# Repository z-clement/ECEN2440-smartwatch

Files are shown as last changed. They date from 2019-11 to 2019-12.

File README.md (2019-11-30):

# ECEN2440-smartwatch

The final project for ECEN2440 Embedded Systems. Our group decided to make a smartwatch that has a touchscreen display
with the capabilities to set an alarm and timer using bluetooth.

The project uses an MSP432 as the microcontroller which communicates via UART with the display and bluetooth module.

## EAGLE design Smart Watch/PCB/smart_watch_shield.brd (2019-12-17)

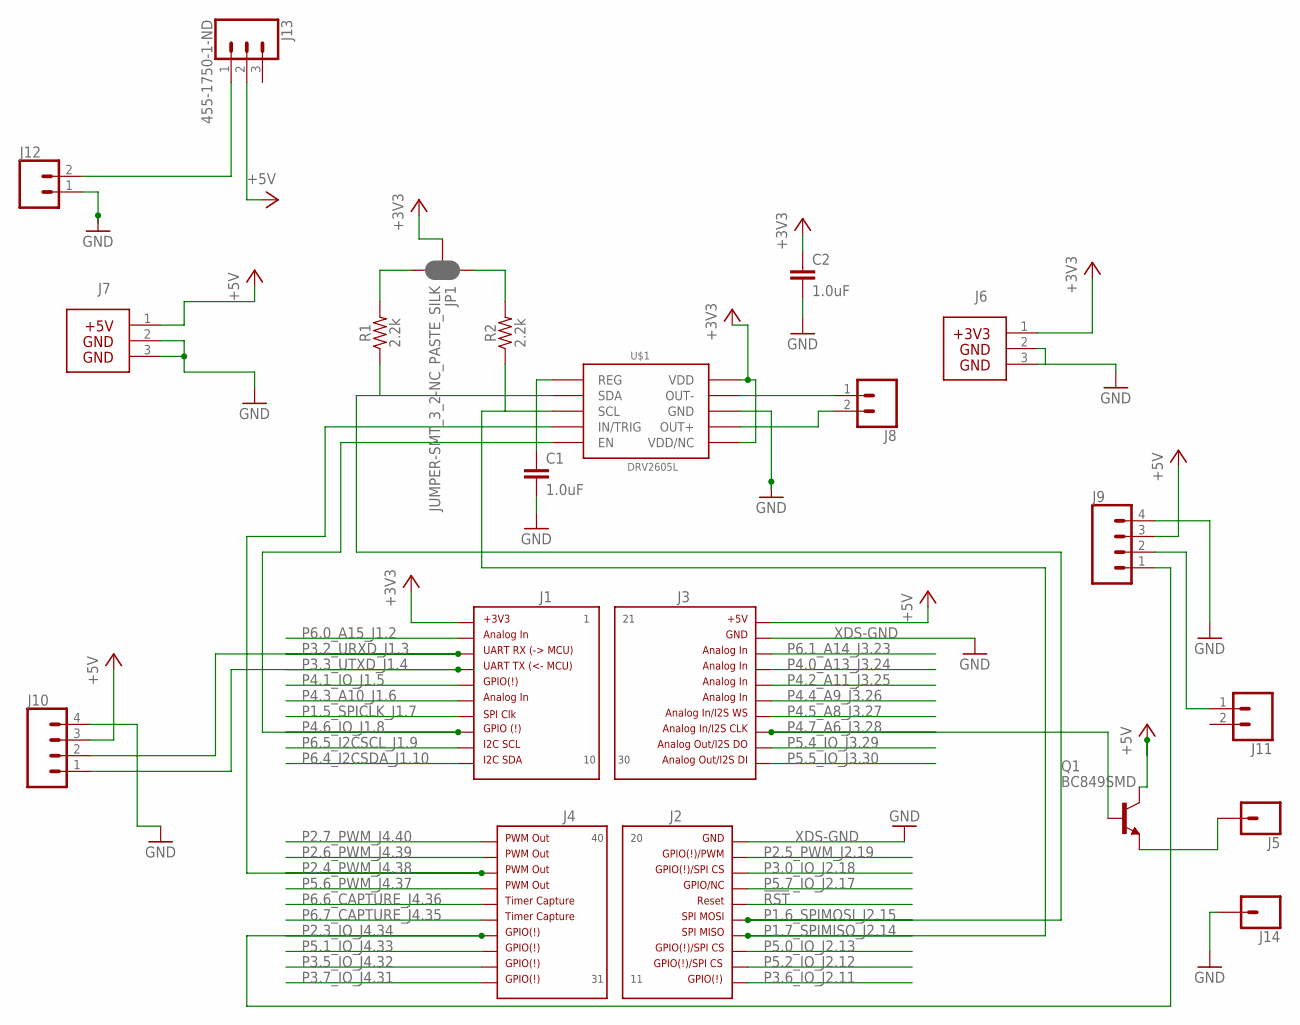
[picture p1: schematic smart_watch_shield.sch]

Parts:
C1, C2: 1.0uF; 0805
J1: HEADER1X10-J1SILK_LABELS; J1
J2: HEADER1X10-J2SILK_LABELS; J2
J3: HEADER1X10-J3; J3
J4: HEADER1X10-J4SILK_LABELS; J4
J5, J14: CONN_01; 1X01
J6: HEADER 1X03; 3PIN_PWR_3V3
J7: BP_HEADERS_PWR_5V; 3PIN_PWR_5V
J8, J11, J12: CONN_02; 1X02
J9, J10: CONN_04PTH; 1X04
J13: 455-1750-1-ND; 1X03
JP1: JUMPER-SMT_3_2-NC_PASTE_SILK; SMT-JUMPER_3_2-NC_PASTE_SILK
Q1: BC849SMD; SOT23-BEC
R1, R2: 2.2k; 0603
U$1: DRV2605L; VSSOP-10

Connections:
!RST: J2.16
+3V3: C2.1, J1.1, J6.1, JP1.2, U$1.P$6 (VDD/NC), U$1.P$10 (VDD)
+5V: J3.21, J7.1, J9.3, J10.3, J13.2, Q1.C
GND: C1.2, C2.2, J6.2, J6.3, J7.2, J7.3, J9.4, J10.4, J12.1, J14.1, U$1.P$8 (GND)
unnamed: JP1.3, R1.2
unnamed: JP1.1, R2.2
unnamed: J8.1, U$1.P$9 (OUT-)
unnamed: J9.2, J11.1
unnamed: J12.2, J13.1
unnamed: J5.1, Q1.E
unnamed: C1.1, U$1.P$1 (REG)
unnamed: J8.2, U$1.P$7 (OUT+)
P1.5_SPICLK_J1.7: J1.7
P1.6_SPIMOSI_J2.15: J2.15, R1.1, U$1.P$3 (SDA)
P1.7_SPIMISO_J2.14: J2.14, R2.1, U$1.P$2 (SCL)
P2.3_IO_J4.34: J4.34, J9.1
P2.4_PWM_J4.38: J4.38, U$1.P$4 (IN/TRIG)
P2.5_PWM_J2.19: J2.19
P2.6_PWM_J4.39: J4.39
P2.7_PWM_J4.40: J4.40
P3.0_IO_J2.18: J2.18
P3.2_URXD_J1.3: J1.3, J10.2
P3.3_UTXD_J1.4: J1.4, J10.1
P3.5_IO_J4.32: J4.32
P3.6_IO_J2.11: J2.11
P3.7_IO_J4.31: J4.31
P4.0_A13_J3.24: J3.24
P4.1_IO_J1.5: J1.5
P4.2_A11_J3.25: J3.25
P4.3_A10_J1.6: J1.6
P4.4_A9_J3.26: J3.26
P4.5_A8_J3.27: J3.27
P4.6_IO_J1.8: J1.8, U$1.P$5 (EN)
P4.7_A6_J3.28: J3.28, Q1.B
P5.0_IO_J2.13: J2.13
P5.1_IO_J4.33: J4.33
P5.2_IO_J2.12: J2.12
P5.4_IO_J3.29: J3.29
P5.5_IO_J3.30: J3.30
P5.6_PWM_J4.37: J4.37
P5.7_IO_J2.17: J2.17
P6.0_A15_J1.2: J1.2
P6.1_A14_J3.23: J3.23
P6.4_I2CSDA_J1.10: J1.10
P6.5_I2CSCL_J1.9: J1.9
P6.6_CAPTURE_J4.36: J4.36
P6.7_CAPTURE_J4.35: J4.35
XDS-GND: J2.20, J3.22

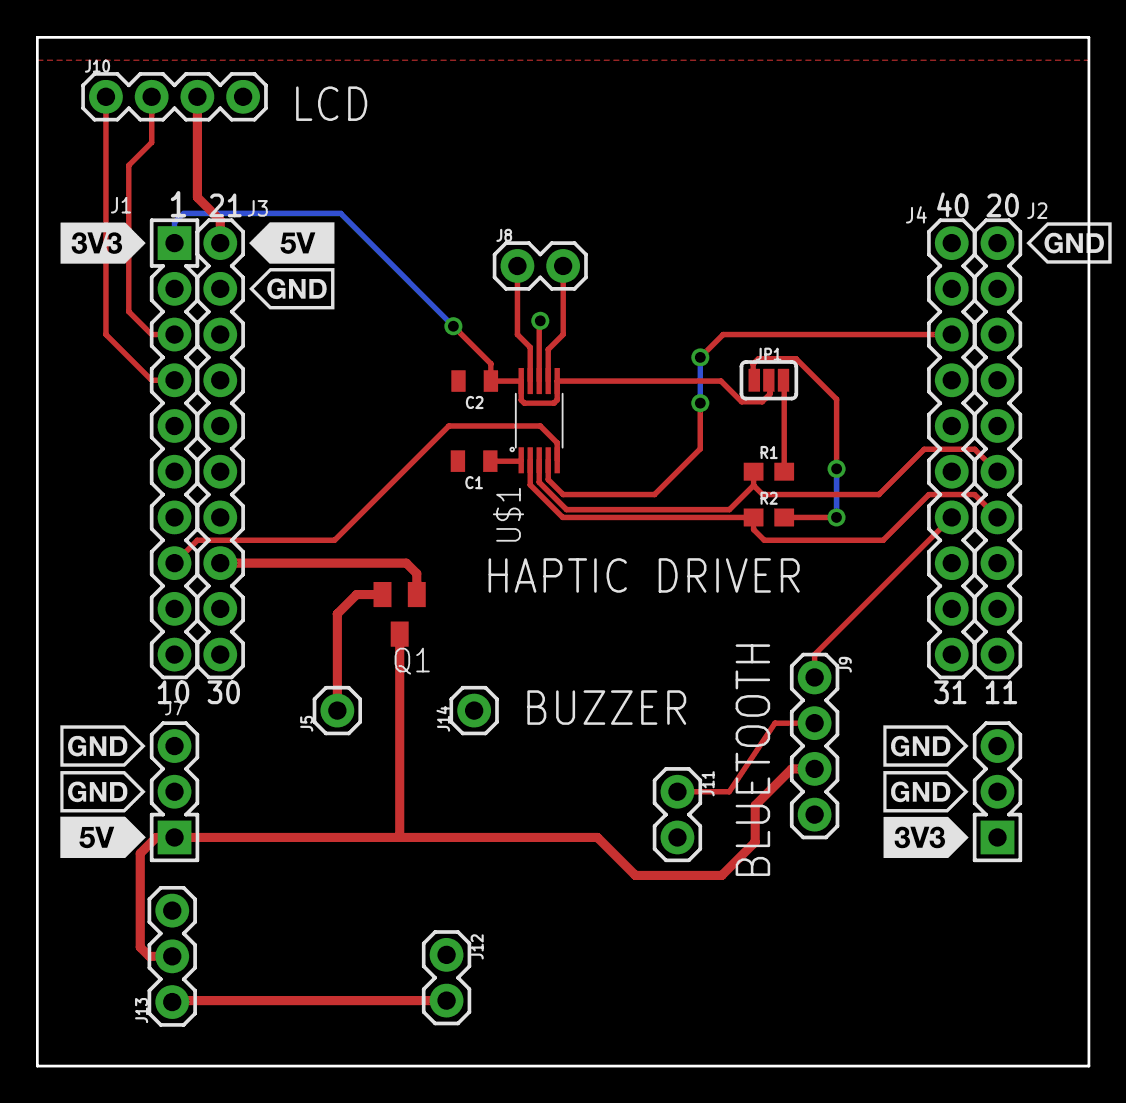
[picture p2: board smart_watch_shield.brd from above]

Board: 2 copper layers, 58.4 x 57.1 mm, 21 parts (1 on the bottom side), 20 nets.

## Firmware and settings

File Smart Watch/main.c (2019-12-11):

#include "msp.h"
#include "uart.h"
#include "bluetooth.h"
#include "circularBuf.h"
#include "screenRefresh.h"
#include "rtc.h"
#include "changeTime.h"
#include "alarmButton.h"
#include "alarm.h"


/**
 * main.c
 */


// Variables to send the current time to the screen
volatile uint8_t sec = 0x00;
volatile uint8_t min = 0x00;
volatile uint8_t hour = 0x00;
volatile uint8_t day = 0x00;
volatile uint8_t month = 0x00;
volatile uint32_t year = 0x00;
volatile uint8_t dow = 0x00;

// Flags for interrupts so we aren't processing a lot of code while in the interrupts
volatile uint8_t MINUTEFLAG = 0;
volatile uint8_t RDYFLAG = 0;
volatile uint8_t ALARMFLAG = 0;
volatile uint8_t TIMERFLAG = 0;
volatile uint8_t RX2FLAG = 0;
volatile uint8_t TX2FLAG = 0;
volatile uint8_t RX1FLAG = 0;
volatile uint8_t TX1FLAG = 0;
volatile uint8_t CLOCKSETFLAG = 0;
volatile uint8_t ALARMSETFLAG = 0;
volatile uint8_t TIMERSETFLAG = 0;
volatile uint8_t ALARMBUTTONFLAG = 0;

// UART variables needed in bluetooth.c and the screen files
EUSCI_A_Type * bluetooth_port = EUSCI_A1;
uint8_t screenData = 0;

void main(void)
{
    WDT_A->CTL = WDT_A_CTL_PW | WDT_A_CTL_HOLD;		// stop watchdog timer

    __enable_irq();

    // Configure buzzer and haptic driver
    config_alarm_notifications();

    // Configure UART for the screen
	EUSCI_A_Type * uart_portScreen = EUSCI_A2;
	config_uart(uart_portScreen);

    // Configure UART for bluetooth
    config_uart(bluetooth_port);

    // Create a circular buffer for bluetooth and screen receiving
    circ_buf_t * bluetoothBuffer = createBuffer(5);
    circ_buf_t * displayBuffer = createBuffer(2);

    // Create a buffer to send a bluetooth message when an alarm fires
    circ_buf_t * alarmBuffer = createBuffer(6);

    // Sends "Connected" over bluetooth to verify the watch is connected
    circ_buf_t * testBuffer = createBuffer(9);
    addMultipleToBuffer(testBuffer, "Connected", 9);
    uart_transmit_buffer(testBuffer, bluetooth_port);
    deleteBuffer(testBuffer);

    // Default time is 12:00:00 on 12/08/2020
    const RTC_C_Calendar currentTime =
    {
         0x00,       // Seconds
         0x00,       // Minutes
         0x12,       // Hours
         0x00,       // Day of week (unused in our watch)
         0x8,        // Day of month
         0x12,       // Month
         0x2020      // Year
    };

    // Configure the RTC with the above time in BCD format
    RTC_config(&currentTime, RTC_C_CTL13_BCD);; // configure the rtc clock and interupts

    // Update the screen with the default time
    clockUpdate();
    changeAllTime(uart_portScreen);

    while(1){
        // Read in from bluetooth UART
        if (RX1FLAG) {
            uart_read_to_buffer(bluetoothBuffer, bluetooth_port);
            if (isBufferFull(bluetoothBuffer)) {
                decode_bluetooth(bluetoothBuffer);
            }
        }
        // Read in from screen UART
        if (RX2FLAG){
            screenReadRegister();
            decode_screen(uart_portScreen);
        }
        // Alarm or timer goes off
        if (ALARMFLAG) {
           // Turn on the Piezo buzzer and haptic driver
           trigger_alarm();
           ALARMFLAG = 0;
           gotoAlarmButton(uart_portScreen);
           // Check if it was a timer, if so disable alarms so the timer doesn't repeat
           if (TIMERFLAG) {
               RTC_C->AMINHR = 0x0000;
               RTC_C->ADOWDAY = 0x0000;
               TIMERFLAG = 0;
               addMultipleToBuffer(alarmBuffer, "Timer", 5);
           } else {
               addMultipleToBuffer(alarmBuffer, "Alarm", 5);
           }

           // Send a message over bluetooth indicating the alarm/timer finished
           uart_transmit_buffer(alarmBuffer, bluetooth_port);
        }
        // Second ticked by, time must be updated
        if (RDYFLAG) {
            clockUpdate();
            // Only update the time if an alarm is not currently going off
            if (ALARMBUTTONFLAG == 0){
                changeAllTime(uart_portScreen);
            }
            RDYFLAG = 0;
        }
    }
}

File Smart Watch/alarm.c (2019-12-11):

/*
 * alarm.c
 *
 *  Created on: Dec 4, 2019
 *      Author: Zac
 */

#include "msp.h"
#include "drv2605l.h"
#include "gpio.h"
#include "i2c.h"
#include "pwm.h"
#include "alarm.h"

// Configure the DRV, LRA, and buzzer
void config_alarm_notifications(void) {
    // Configurations for drv and haptic driver
    // configure the I2C
    config_i2c();
    // configure the timer
    config_pwm_timer();
    // configure GPIO on P2.4
    config_pwm_gpio();
    // configure the DRV2605L
    config_drv2605L();

    // Configurations for buzzer pins
    config_buzzer_gpio();
}

// Turn the drv and buzzer on
void trigger_alarm(void) {
    // Turn the drv on
    start_pwm(90);
    // Turn the buzzer on
    P4->OUT |= BIT7;
}

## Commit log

2019-11-27 Working circular buffer & parameterized uart
2019-11-27 Fixed errors with EUSCI as a parameter
    [bluetooth.c, main.c, uart.c]
2019-11-28 Updated example with screenRefresh.c allowing for uart comunication using both EUSCI_A1 and EUSCI_A2.
2019-11-28 Updated screen testing string to have termination characters on both sides of message. Also begining to implimnet the RTC fuctionality with uart functionality.
2019-11-29 In clock.c looking at the registers while debugging, everything seems to be working, however the minuete interupt flag gets set, but nothing happens. Will continue to search for the error tomorrow.
    [main.c]
2019-11-30 Non working code
    In the debugger the value of MINUTEFLAG changes, however in the while
    loop the value of MINUTEFLAG is never not 1. When running the debugger
    the value of MINUTE flag goes to 1 but then it does not call the
    clockUpdate function. Not sure why this is happening. Also in the debug
    the stack pointer gets lost at certain points and the onboard LEDs do
    not light up.
2019-11-30 Changed around uart interrupt setup, implemented alarm and timer on rtc
2019-12-02 # WARNING: head commit changed in the meantime
    Fixed clock update issues. Added clock update functions.
    [main.c]
2019-12-05 Added in DRV, PWM, and GPIO code for buzzer & DRV
    [alarm.c, drv2605l.c, gpio.c]
2019-12-05 Working alarm button
2019-12-09 Fixed bug where haptic driver wouldn't shut off.
2019-12-09 Reset so the alarm will start in the off position.
    [main.c]
2019-12-17 Created folder for PCB files

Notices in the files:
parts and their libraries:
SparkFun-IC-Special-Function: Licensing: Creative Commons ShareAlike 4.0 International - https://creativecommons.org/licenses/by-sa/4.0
